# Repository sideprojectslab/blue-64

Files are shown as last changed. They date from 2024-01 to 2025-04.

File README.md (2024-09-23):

# Blue-64

If you would like to get in touch with the developer, please join the SPL [Discord](https://discord.gg/gJsCgebkDw) server.

[FULL README (PDF)](https://raw.githubusercontent.com/sideprojectslab/blue-64/main/doc/README.pdf)

Blue-64 is a plug & play bluetooth adapter for the Commodore 64 that plugs onto the keyboard header inside the computer and can control the keyboard lines and emulate keystrokes and joystick inputs. The goal of the project is to support two bluetooth controllers and a bluetooth keyboard simultaneously, in order to be able to controll the C64 completely wirelessly.

<figure align="center" id="blue_64_reg">
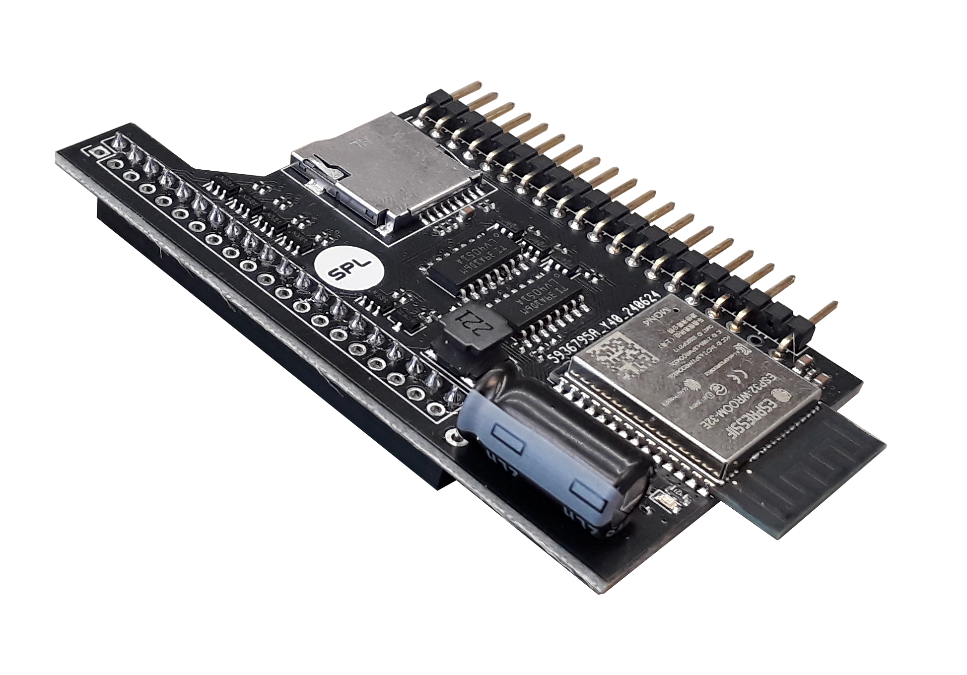
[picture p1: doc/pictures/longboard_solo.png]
	
	<figcaption>Blue-64 "Regular" Board</figcaption>
</figure>

<figure align="center" id="blue_64_dev">
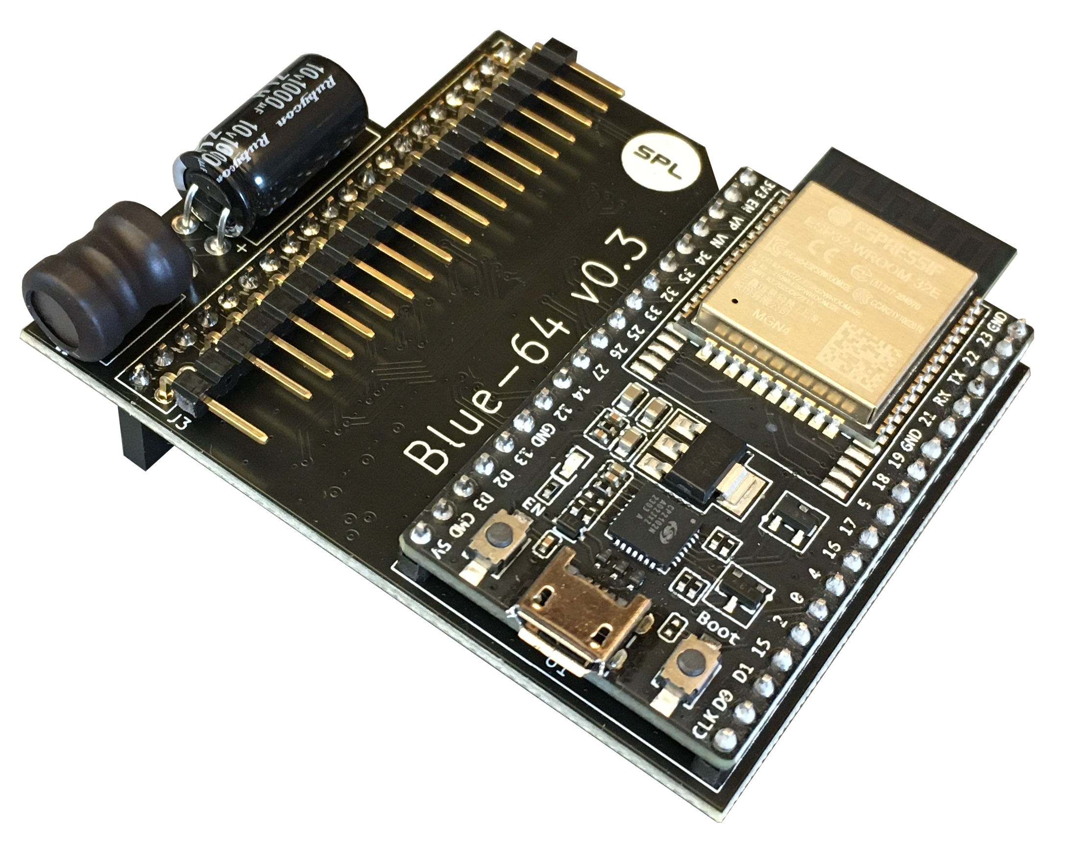
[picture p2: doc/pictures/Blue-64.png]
	
	<figcaption>Blue-64 Developer Board</figcaption>
</figure>

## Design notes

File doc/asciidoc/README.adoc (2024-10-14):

= Blue-64
:pdf-theme: resources/theme.yml
include::../resources/header.adoc[]
include::../resources/styles.adoc[]

ifndef::root[:root: ../../]
ifndef::firmware_update[:firmware_update:]
ifndef::misc[:misc:]
ifndef::mapping[:mapping:]
ifndef::menu[:menu:]

**Author:** Vittorio Pascucci

If you wish to get in touch with the developer, please join the SPL link:https://discord.gg/gJsCgebkDw[Discord] server.

**LICENSE:**
This work is provided under the **Creative Commons CC BY-NC-ND 4.0** License: +
https://creativecommons.org/licenses/by-nc-nd/4.0/

[cols="100a,113a"]
[width=80%]
[.center, frame=none, grid=none]
|===
|.Blue-64-developer ("Developer" Board)

|.Blue-64-regular ("Regular" Board)

|===

Blue-64 is a plug & play bluetooth adapter for the Commodore 64 that plugs onto the keyboard header inside the computer and can control the keyboard lines and emulate keystrokes and joystick inputs. The goal of the project is to support two bluetooth controllers and a bluetooth keyboard simultaneously, in order to be able to controll the C64 completely wirelessly.

Blue-64 can be purchased pre-assembled or as a DIY-Kit from these authorized shops:

- link:https://retro8bitshop.com/product/spl-blue-64-v1/[Retro8BitShop]
- link:https://www.retro-updates.com/product/15909946/blue-64-v1-0-plug-play-bluetooth-for-the-c64[Retro-Updates]
- link:https://restore-store.de/home/682-blue-64-v03.html?search_query=blue-64&results=7[Restore-Store]

Sales of Blue-64 by any shop other than the ones mentioned above may be in violation of the xref:#_license[License] terms and conditions and should be reported to the developer

<<<
toc::[]
<<<

== Pairing a Bluetooth Device
The Blue-64 is **always listening to incoming pairing requests** up to a maximum of three devices paired simultaneously. This means that it is sufficient to simply set a Bluetooth controller or keyboard in pairing mode and it will automatically pair with the Blue-64 without the need to set the Blue-64 itself in pairing mode.

include::mapping.adoc[]

include::menu.adoc[]

include::compatibility.adoc[]

include::firmware_update.adoc[]

include::misc.adoc[]

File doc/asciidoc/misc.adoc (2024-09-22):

include::../resources/header.adoc[]
include::../resources/styles.adoc[]
ifndef::root[:root: ../../]

== Installation & Precautions
Most notably, particular care shall be used when plugging the Blue-64 onto the motherboard, as the female connector on the Blue-64 has no alignment key and thus won't prevent incorrect installation. Always install the Blue-64 with the computer turned off and verify carefully that the connection to the motherboard header is properly aligned.

A step-by-steb video guide on how to assemble and install the Blue-64 board is available on link:https://youtu.be/yE2yL8-_jRQ?si=YmAZqs-F023yzRW5[YouTube]:
Users shall follow these instructions carefully and fully understand the circuit's limitations before installing and/or using it.

Incorrect installation of the board supply or failure to comply with the recommended operating conditions may result in damage to the board and/or to the computer, with risk of overheating, fire and/or explosion.

== License
License information is included on top of all software source files as well as in all schematics. Files that do not contain explicit licensing information are subject to the licensing terms stated in the LICENSE.txt provided in the main project folder:

Unless stated otherwise in individual files, all hardware design Schematics, Bill of Materials, Gerber files and manuals are licensed under Creative Commons Attribution-NonCommercial-NoDerivatives 4.0 International. To view a copy of this license, visit http://creativecommons.org/licenses/by-nc-nd/4.0/

Unless otherwise stated in individual files, all software source files are Licensed under the Apache License, Version 2.0. You may obtain a copy of this license at http://www.apache.org/licenses/LICENSE-2.0

== Disclaimer
All material is provided on an 'AS IS' BASIS, WITHOUT WARRANTIES OR
CONDITIONS OF ANY KIND in accordance to the license deed applicable to
each individual file.

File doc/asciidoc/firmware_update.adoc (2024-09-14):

include::../resources/header.adoc[]
include::../resources/styles.adoc[]
ifndef::root[:root: ../../]

:on-screen-menu: xref:{menu}#menu[on-screen menu]
:github: link:https://github.com/sideprojectslab/blue-64/[GitHub]

== Firmware Update
Firmware binaries can be found in the "Releases" section of the project's {github} page. The three files in the "binaries.zip" folder are necessary to perform a firmware update:
- bootloader.bin
- partition-table.bin
- application.bin

=== "Developer Boards" (up to v0.3)

NOTE: It is not possible to "brick" the "Developer Board", if something fails it will always be able to re-try flashing new firmware.

. Connect the Blue-64 to the PC through a data-capable Micro-USB cable. The power led on the Blue-64 board shall turn on.

. Download and install the CP210X Universal Windows Drivers for the on-board programmer at this website:
https://www.silabs.com/developers/usb-to-uart-bridge-vcp-drivers?tab=downloads

. Open the Espressif Online Tool in a web browser at the following link: https://espressif.github.io/esptool-js/

+
.ESP Online Tool: Start Screen
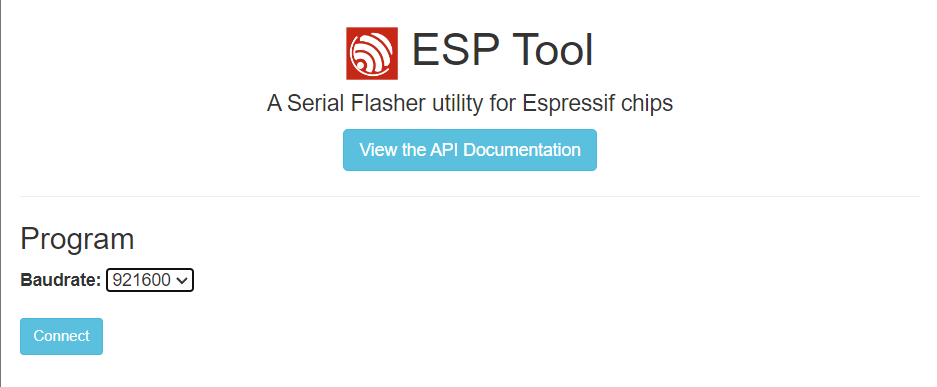
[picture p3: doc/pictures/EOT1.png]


. Select the highest Baudrate and click "connect". The dialog shown below shall appear, allowing the selection of the currently connected Blue-64
+
.ESP Online Tool: Device Selection
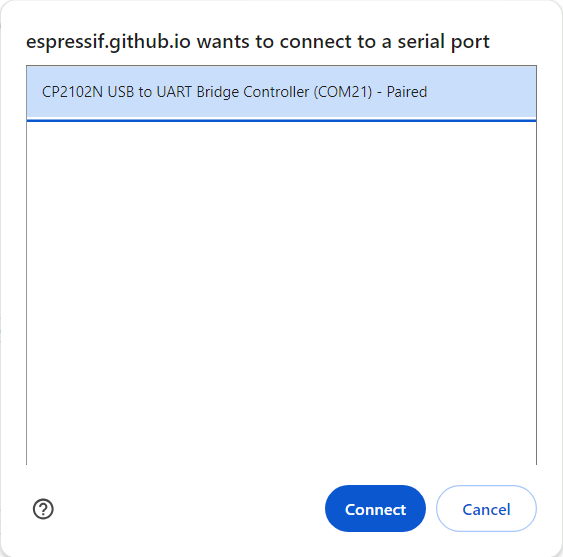
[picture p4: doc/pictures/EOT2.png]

+
NOTE: if pressing the "connect" button on the start screen does not open the dialog above, please try opening the web page with a different web browser.

. Once connected, add the update files at the appropriate addresses so that the page looks like the picture below
+
.ESP Online Tool: Binary Upload
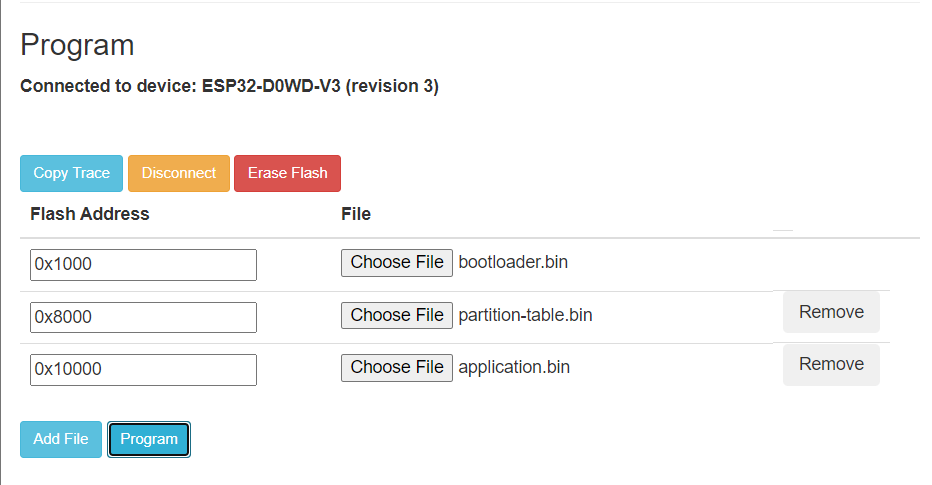
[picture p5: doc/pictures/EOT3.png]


. Press "program". If everything went well, the console below should look like the picture below
+
.ESP Online Tool: Successful Update
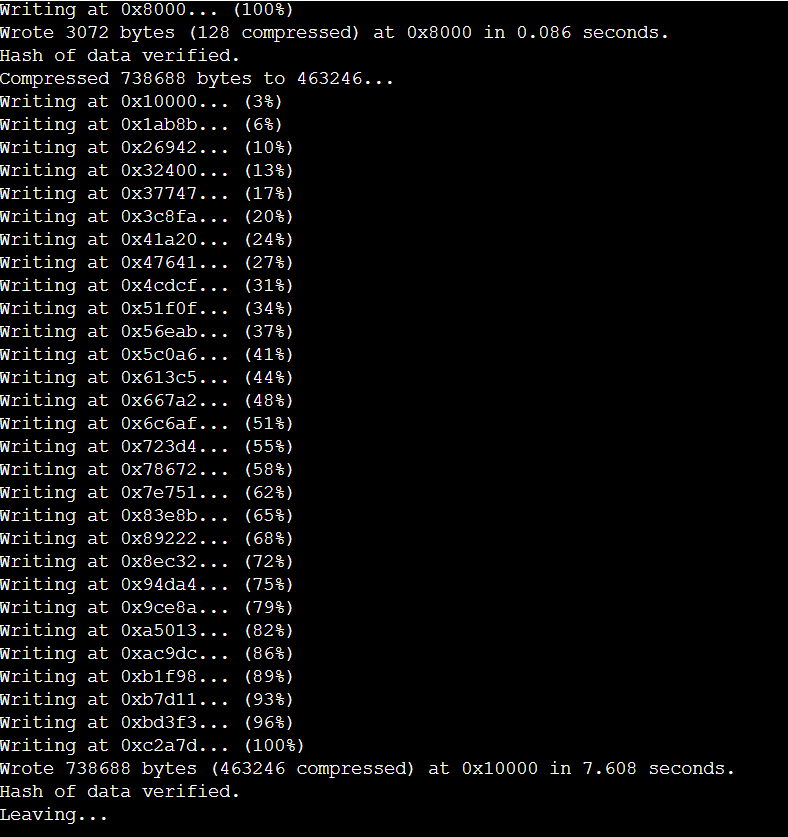
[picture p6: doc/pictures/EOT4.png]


=== "Regular Boards" (v1.0 and above)
Regular boards are updated via the Micro SD card slot.

. Format a Micro SD card to FAT32.
. Copy application.bin to the root of the SD card.
. Switch off the C64 and insert the SD card into the dedicated slot on the Blue-64 board.
. Switch on the C64, after a few seconds an on-screen prompt will state that the update has started. If the prompt does not appear within 10 seconds it means that the ESP cannot mount the SD card or cannot find the application.bin file in its root.

NOTE: DO NOT POWER OFF THE C64 DURING THIS PROCESS UNLESS IT TAKES MORE THAN 10 MINUTES

. After about a minute an on-screen prompt will communicate the result of the update procedure.
. Switch off the C64, remove the SD-Card and switch on again.
, Navigate to the Device-Info entry on the {on-screen-menu} and verify that the latest version is currently running on the device.

NOTE: In the extremely unlikely event that the device becomes "bricked" (as in not functioning properly and also not being able to accept new firmware), it is **always possible** to flash new firmware via the UART header on the bottom of the board. This can be done with an inexpensive USB-to-UART adapter and basic soldering skills. Please get in touch with the developer for support.

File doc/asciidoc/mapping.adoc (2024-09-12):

include::../resources/header.adoc[]
include::../resources/styles.adoc[]
ifndef::root[:root: ../../]
ifndef::menu[:menu: menu.adoc]

:on-screen-menu: xref:{menu}#menu[on-screen menu]
:vice: xref:https://vice-emu.sourceforge.io/vice_1.html#SEC11[Vice]

== Controller Mapping (xInput)

The following key mappings directly apply to "xInput" devices, such as the Xbox-One controller. Different controllers such as the Switch controller and the Playstation 4/5 controller have nearly identical mapping, where buttons in similar positions perform the same function as their xInput counterparts

[%header, cols="^.^, ^.^, ^.^"]
[width=80%]
[.center]
|===
| Joystick | Controller  | Controller Alt.
| UP       | D-Pad UP    | Button B
| DOWN     | D-Pad DOWN  | Button X
| LEFT     | D-Pad LEFT  | Left Analog
| RIGHT    | D-Pad RIGHT | Left Analog
| FIRE     | Button A    | Button Y (Autofire)
|===

[[button-map]]
Controller buttons not mentioned in the table above can be mapped to trigger any keyboard keystroke through the {on-screen-menu}. Default Controller-Keyboard mappings are reported below:

[%header, cols="^.^, ^.^"]
[width=80%]
[.center]
|===
| Keyboard | Controller
| SPACE    | Menu Button
| F1       | Right Shoulder
|===

[[autofire]]
=== Autofire
The "Y Button" is dedicated to autofire, which can be configured from inactive to 10Hz (100ms) fire-rate through the {on-screen-menu}

[[swap-ports]]
=== Swapping Joystick Ports
Joystick ports assigned to the connected bluetooth controllers can be swapped with the "View + Y" key combination on the controller.
If two controllers are currently connected, only the controller currently assigned to joystick port 2 can swap the ports (to prevent pesky little siblings or partners from swapping ports in-game)

[[keyboard-map]]
== Keyboard Mapping
At the moment Blue-64 **only supports the English US layout**. The key mapping can be switched between "symbolic" and "positional ({vice})" through the {on-screen-menu}. With "symbolic" mapping the keys on the bluetooth keyboard do exactly what they say on the label, including their "shift" function (if applicable) with a few exceptions:

[%header, cols="^.^, ^.^"]
[width=80%]
[.center]
|===
| En-US Key (symbolic) | C64 Key
| '~'             | Arrow Left
| '\'             | Arrow Up
| 6+Shift         | £
| Tab / Shift+Tab | Stop / Run
| Esc             | Restore
| Delete, F12     | Clear
| Home, F9        | Home
| Insert, F10     | Insert
| Start (Windows) | Commodore
| Shift+'\'       | Pi
|===

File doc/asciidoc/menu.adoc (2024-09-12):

include::../resources/header.adoc[]
include::../resources/styles.adoc[]
ifndef::root[:root: ../../]
ifndef::mapping[:mapping: mapping.adoc]

:keyboard-mapping-profile: xref:{mapping}#keyboard-map[keyboard mapping profile]
:unused-controller-buttons: xref:{mapping}#button-map[unused controller buttons]
:autofire: xref:{mapping}#autofire[Autofire]

[[menu]]
== On-Screen Menu & Additional Functions
Blue-64 has an internal menu that is visualized by printing text on screen. The menu allows typing and executing frequently used macros like loading the tape, loading and/or running programs from disk drive etc. as well as configuring additional preferences.

=== Navigating the On-Screen Menu (xInput)
. The on-screen menu can only be navigated via a connected bluetooth controller and/or keyboard and **not with the native C64 keyboard**
. In order to **Enter** the on-screen menu simply press "View + A/B" on the controller or "Alt/AltGr + Up/Down/Left/Right Arrow" on the keyboard, and menu entries will start printing on screen
. Once inside the on-screen menu, in order to move or **"Cycle"** through the varius entries press "View + A/B" on the controller or "Alt/AltGr + Up/Down/Left/Right Arrow" on the keyboard
. In order to **Exit** the on-screen menu or any submenu press "View + X" on the controller or "Alt/AltGr + Backspace" on the keyboard. This will bring the menu "back one level" or produce a blank screen when exiting the menu completely
. In order to **Confirm** a choice press "View + Menu" on the controller or "Alt/AltGr + Enter" on the keyboard

//-

[%header, cols="^.^, ^.^, ^.^"]
[width=80%]
[.center]
|===
| Function         | Controller Button(s) | Keyboard Key(s)
| Enter/Cycle Menu | View + A/B           | Alt/AltGr + Up/Down/Left/Right Arrow
| Confirm Menu     | View + Menu          | Alt/AltGr + Enter
| Exit Menu        | View + X             | Alt/AltGr + Backspace
|===

NOTE: Pressing "View + Menu" on the controller or "Alt/AltGr + Enter" on the keyboard outside of the on-screen menu will launch the last displayed entry. If no entry was yet displayed, the **"LOAD TAPE"** entry will be launched.

NOTE: Please beware that the "view" and "menu" buttons may be called differently on non xInput devices but are generally in similar positions

NOTE: Please beware that some controllers, such as 8bitDo or Switch controllers have X-Y and A-B button labels swapped compared to a regular Xbox controllers. What matters in this case is the buttons' position, not the label, so for instance the A button will always be the one at the bottom regardless of the label

=== Loading Tape/Disk
The first entries of the on-screen menu allow to quickly launch commonly used commands:

. **LOAD TAPE:** LOAD
. **LOAD DISK:** LOAD$,8
. **RUN DISK:** LOAD*,8

In order to launch these commands:

. **Enter** the on-screen menu
. **Cycle** to find the desired command
. **Confirm** (The appropriate command will be automatically typed on-screen and run)

NOTE: When loading the tape it is often necessary to press "space" on the keyboard to run the first program. The "space" key is also mapped by default on the "Menu" button of the controller

=== Checking Device information
The **"DEVICE INFO"** menu entry shows relevant information about the device, including the firmware version. In order to display the device info:

. **Enter** the on-screen menu
. **Cycle** to find the "DEVICE INFO" entry
. **Confirm**
. Once the device information is plotted on screen, **Exit** the (sub)menu

=== Selecting Keyboard Mapping
The {keyboard-mapping-profile} can be switched between "symbolic" and "positional". In order to select the desired profile:

. **Enter** the on-screen menu
. **Cycle** to find the "KEYBOARD MAPPING" entry
. **Confirm** to enter the submenu
. **Cycle** to select the desired profile
. **Confirm** (this will also exit the submenu)
. **Exit** the menu

=== Configuring Autofire Rate
{autofire} rate can be configured between "none" (single shot) to 10Hz (10 shots per second) through the on-screen menu. In order to configure the autofire rate:

. **Enter** the on-screen menu
. **Cycle** to find the "AUTOFIRE RATE" entry
. **Confirm** to enter the submenu
. **Cycle** to select the desired rate
. **Confirm** (this will also exit the submenu)
. **Exit** the menu

=== Mapping Controller Buttons to Keyboard Keys
All {unused-controller-buttons} can be remapped to trigger keyboard keystrokes through the on-screen menu. In order to assign keystrokes to controller buttons:

. **Enter** the on-screen menu
. **Cycle** to find the "CONTROLLER MAPPING" entry
. **Confirm** to enter the submenu
. **Cycle** to find the controller button you wish to assign a keystroke to

NOTE: While cycling through the controller buttons, the currently assigned keystroke is shown on the right. If no keystroke is assigned to the currently displayed button the **""** (empty) symbol is shown

. **Confirm** to select the currently displayed controller button
.. To leave the current association unchanged **Exit** the (sub)menu immediately
.. To remove the current keystroke association **Confirm** immediately
.. If a bluetooth keyboard is connected, press the desired key (including modifiers) on the bluetooth keyboard, then **Confirm**
.. If no bluetooth keyboard is connected, **Cycle** until the desired key is displayed on the right, then **Confirm**.
. Any of the aforementioned actions will also deselect the current button
. **Cycle** to find another desired button to assign a keystroke to
. Repeat the steps above until all desired buttons have been mapped
. **Exit** the (sub)menu

=== Restoring Default Settings
Default settings can be restored through the on-screen menu. In order to restore default settings:

. **Enter** the on-screen menu
. **Cycle** to find the "RESTORE DEFAULTS" entry
. **Confirm** to enter the submenu
. **Cycle** to select "YES"
. **Confirm** (this will also exit the submenu)
. **Exit** the menu

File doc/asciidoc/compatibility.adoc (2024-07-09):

include::../resources/header.adoc[]
include::../resources/styles.adoc[]
ifndef::root[:root: ../../]

== Compatibility

=== C64 Motherboard Compatibility
Blue-64 has been verified to be compatible with the following C64 motherboard revisions:

[%header, cols="^.^1, ^.^2"]
[width=80%]
[.center]
|===
| Motherboard | Notes
| 250407  | -
| 250425  | -
| 250466  | -
| 326298  | -
| ku14194 | -

| 250469
| The developer version of Blue-64 needs a xref:#shortboard-adapter[special adapter] and the female header is mounted upside down
|===

.Shortboard Adapter
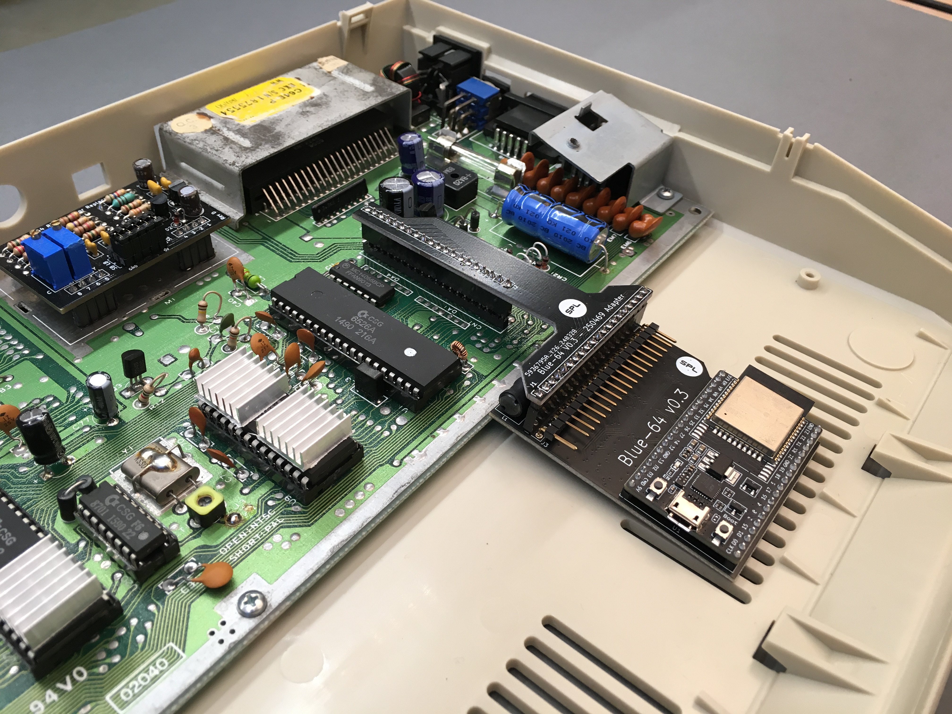
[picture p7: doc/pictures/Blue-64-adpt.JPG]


=== Device Support
Blue-64 is based on the link:https://bluepad32.readthedocs.io/en/latest/[bluepad32] library from Ricardo Quesada. As such it supports the exact same devices (bluetooth controllers & keyboards) as bluepad32.

Supported Controllers: https://bluepad32.readthedocs.io/en/latest/supported_gamepads/

Supported Keyboards: https://bluepad32.readthedocs.io/en/latest/supported_keyboards/

=== Limitations
- At the moment Blue-64 only supports Bluetooth Low Energy (BLE) devices.

- Blue-64 can only interact with the lines present on the keyboard header, thus it has no access to the "paddle" control lines. Therefore it cannot emulate the Commodore mouse, paddle controls, and does **not support additional joystick fire buttons** (other than the primary one) that are based on paddle control. Luckily though, most games supporting additional fire buttons also map them to keyboard keys, which can be mapped to controller buttons through the on-screen menu.

- Blue-64 can only perform **one keystroke at a time**, with the exception of modifier keys like ``control``, ``commodore``, ``left-shift`` and ``restore`` which can all be pressed simultaneously. In order to overcome this limitation, when multiple regular keys are pressed simultaneously, Blue-64 **always performs the latest keypress**. At the same time it remembers the order of the last 8 simultaneous keystrokes, in order to trigger new keystrokes in the inverse order when the current one is released.

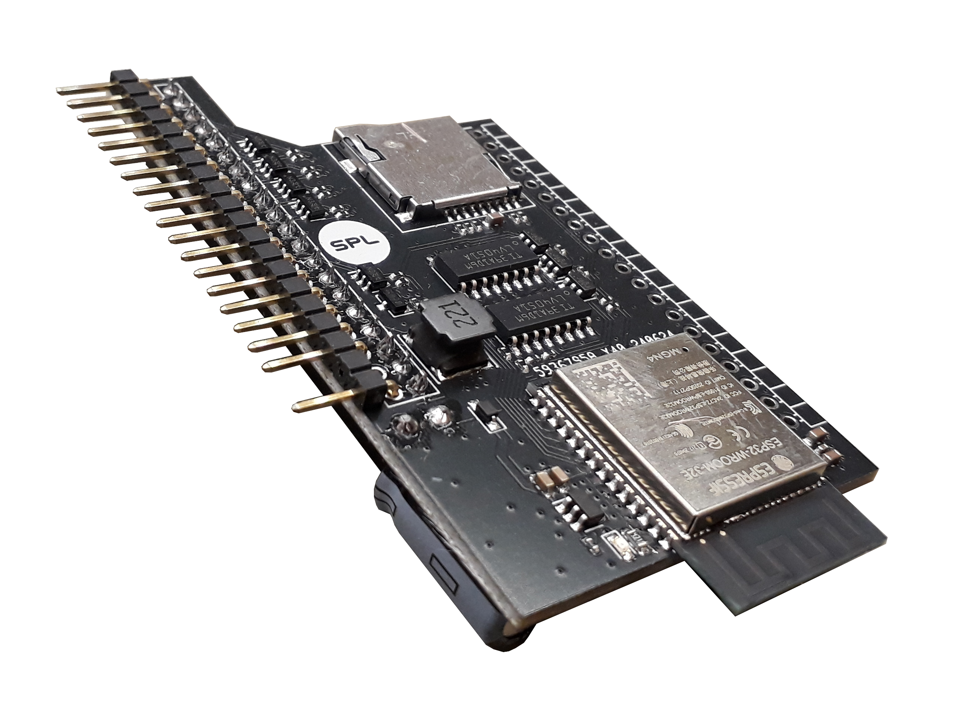
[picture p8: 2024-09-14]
doc/pictures/shortboard_solo.png

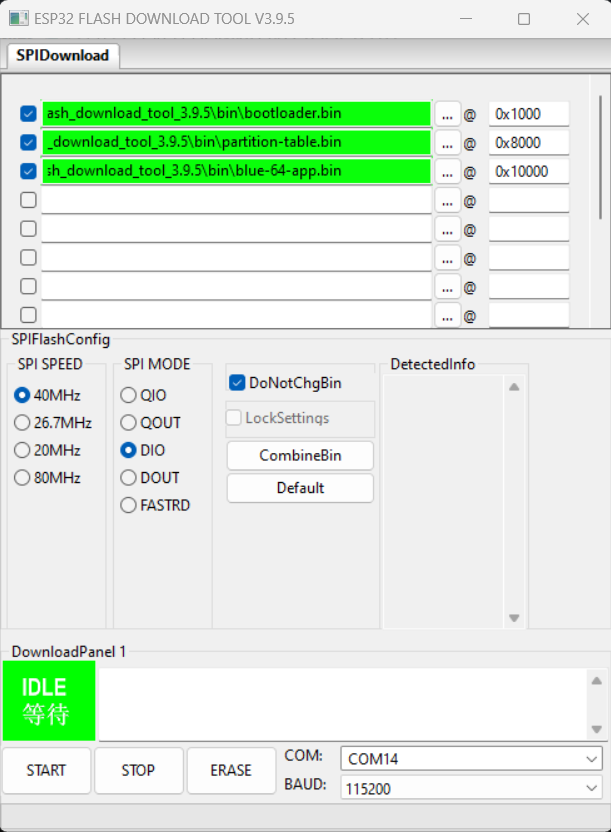
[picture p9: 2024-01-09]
doc/pictures/flash_tool.png

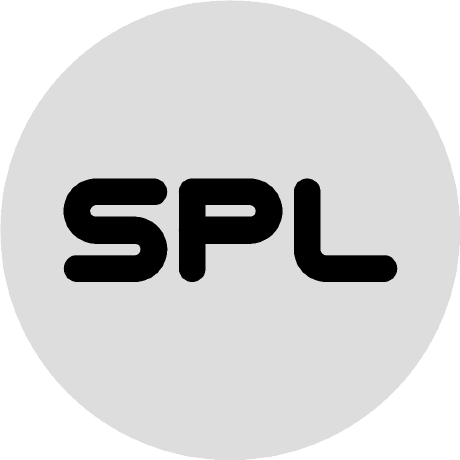
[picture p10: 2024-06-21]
doc/pictures/spl.png

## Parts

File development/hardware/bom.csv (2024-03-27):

Comment | DNP | Designator | Footprint
10ZLH1000MEFC8X16 |  | C1 | eas_cdb_capacitor:10ZLH1000MEFC8X16-Horiz-L
B5819WS-TP |  | D1 | eas_cdb_diode:D_SOD-323_HandSoldering
BC817-40,235 |  | Q1 | eas_cdb_bjt:SOT-23
RC0603FR-0710KL |  | R1, R2, R3, R4, R5, R6, R7, R8, R9, R10, R11, R12, R13, R14, R15, R16, R17, R18, R19, R20, R21 | eas_cdb_resistor:R_0603_1608Metric
BC817DS,115 |  | U2, U3, U4, U5, U6 | eas_cdb_bjt:TSOP-6_1.65x3.05mm_P0.95mm
MC74LVXT4051DR2G |  | U7, U8 | eas_cdb_switch_solid_state:SOIC-16_3.9x9.9mm_P1.27mm
TS5A1066DBVR |  | U9, U10, U11 | eas_cdb_switch_solid_state:SOT-23-5

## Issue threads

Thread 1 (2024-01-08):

C128 keyboard support?

banman11, 2024-01-08:
Hello,

First up, I'd like to say this looks like a very interesting project.

I was wondering how hard would it be to add a few extra keystrokes to support the very few extra keys on a C128 keyboard?

sideprojectslab, 2024-01-08:
Hello, as long as the hardware allows it it should be no problem. However I
need to look into the keyboard connector of the c128 to say for sure :)

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

banman11, 2024-01-08:
The keyboard is basically the same thing as a C64 with a few extra lines. One is hardwired I believe. That is the 40/80 switch.
The actual interface is a sort of square 25 way D female connector.
The Commodore engineer's tried to make it as easy as possible to use off the shelf parts.

Here is an example of a third party adaptor which would very easily plug straight into your project.

https://www.tindie.com/products/retrofletch/c64-keyboard-to-c128-adaptor-commodore-128-c128d/

Just a side note with a small wiring rearrangement of the keyboard lines a c16/plus4 keyboard should work just fine as well.

https://www.pcbway.com/project/shareproject/C64_Keyboard.html

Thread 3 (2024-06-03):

Does it come preflashed?

ssuukk, 2024-06-03:
Hi!

I've just received an assembled version of Blue 64. The passthrough seems to work ok, as I can type on C64 keyboard, but the device itself keeps sending ghost keypresses (probably every second, not exactly random, the letters seem to repeat). Do I have to flash it? Can I debug it somehow?

sideprojectslab, 2024-06-10:
Hi, sorry for the late reply. Either the board is defective or (more likely) it is stuck in a boot loop. Normally the boards come already flashed but who knows, yours might have been corrupted somehow. There are a few steps you can take: first of all I would suggest to follow the instructions on the readme here on github and make sure to flash the latest version of the firmware. If that doesn't fix your issue we can go on with debugging. Would you be able to build the project yourself on Windows with some guidance? This would make the debugging process very easy, otherwise I will provide you with a debug-enabled version of the firmware which will log all diagnostics on a UART terminal through the USB port

ssuukk, 2024-06-10:
Sure, I have a few ESP32 projects, so I guess I can manage with debuggin this one!

sideprojectslab, 2024-06-11:
allright perfect, would you like to join the discord server linked in the project readme? then we can troubleshoot more easily :)

ssuukk, 2024-06-11:
sure, which one? :D

sideprojectslab, 2024-06-14:
This one: https://discord.com/invite/gJsCgebkDw I am not aware of any others :D

ssuukk, 2024-06-22:
Oh, there's thousands of them! Check out this cool one about Meatloaf - a C64 cloud drive on ESP!

Closed 2024-12-27.

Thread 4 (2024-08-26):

Compatibility with Ultimate64 Elite?

pwartbichler, 2024-08-26:
Hi,
Is this project compatible with the current version of the Ultimate64 Elite, and will it support upcoming versions?

Thanks!

sideprojectslab, 2024-08-26:
Hello,

The Blue-64 can be used on the current version of the U64 by means of a
ribbon cable to relocate the board in an appropriate position. Gideon was
not planning to support reading joystick data from the keyboard header in
future version of the U64, which would make the blue-64 much less useful.
Fortunately I have been talking to him and he seemed to confirm that it
would be possible to enable this feature via software in future versionn of
the U64, so I'll keep you posted on the progress.

The best way to stay up to date is to join our discord server, where you
can also ask around other users that have been experimenting with the
Blue-64.

https://discord.gg/w6gvqyBG

Kind regards,

On Mon, Aug 26, 2024 at 10:39 AM Patrik Wartbichler <
***@***.***> wrote:

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

pwartbichler, 2024-08-27:
Thanks for the update, this sounds very promising 👍

Closed 2024-12-27.

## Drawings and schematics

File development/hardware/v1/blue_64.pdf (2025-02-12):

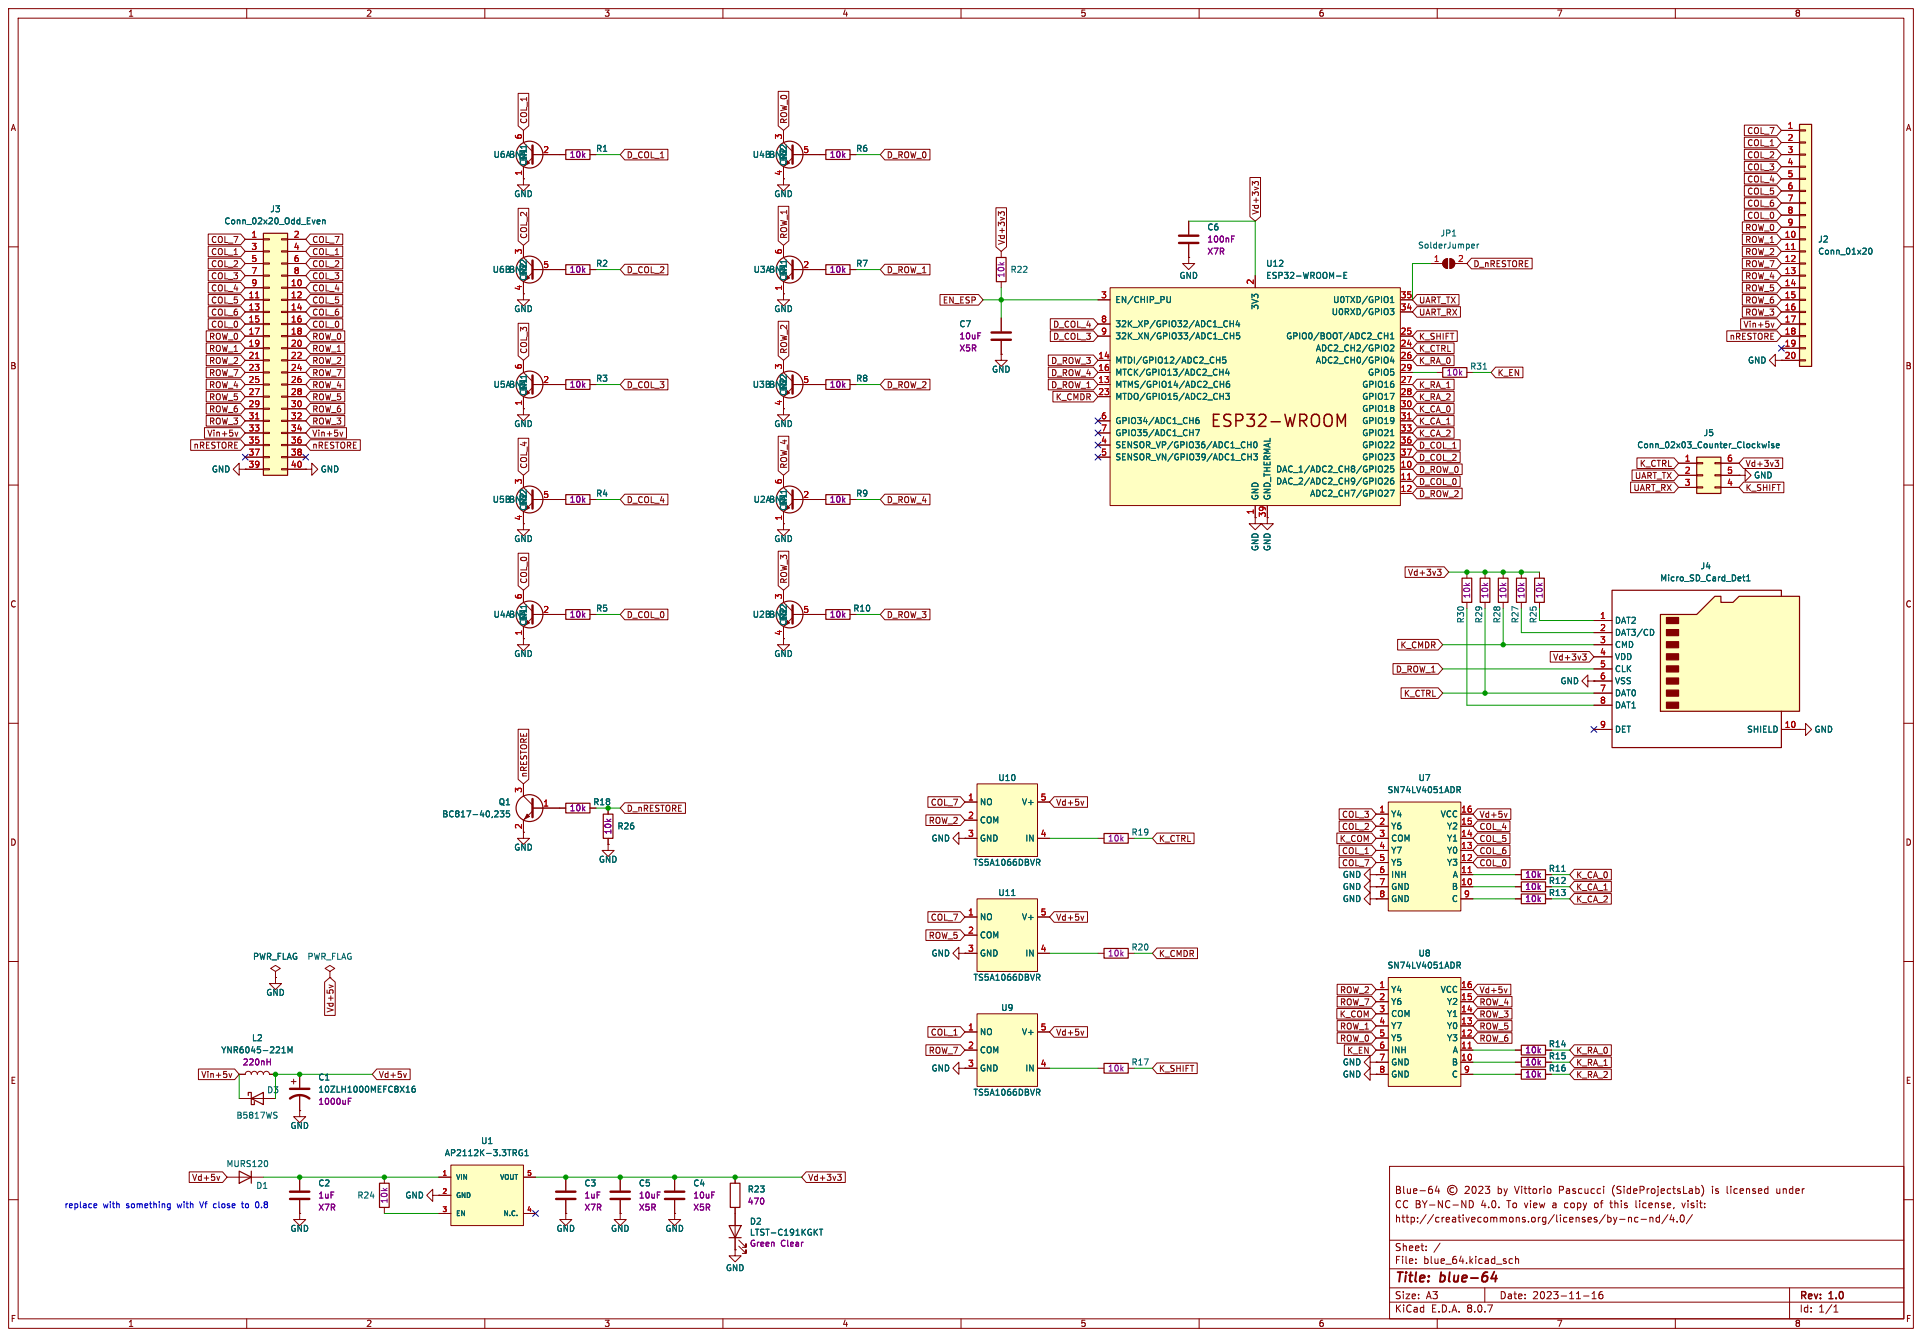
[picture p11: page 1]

10 DAT3/CD 2 CMD 3 VDD 4 CLK 5 VSS 6 DAT0 7 DAT1 8 DET 9

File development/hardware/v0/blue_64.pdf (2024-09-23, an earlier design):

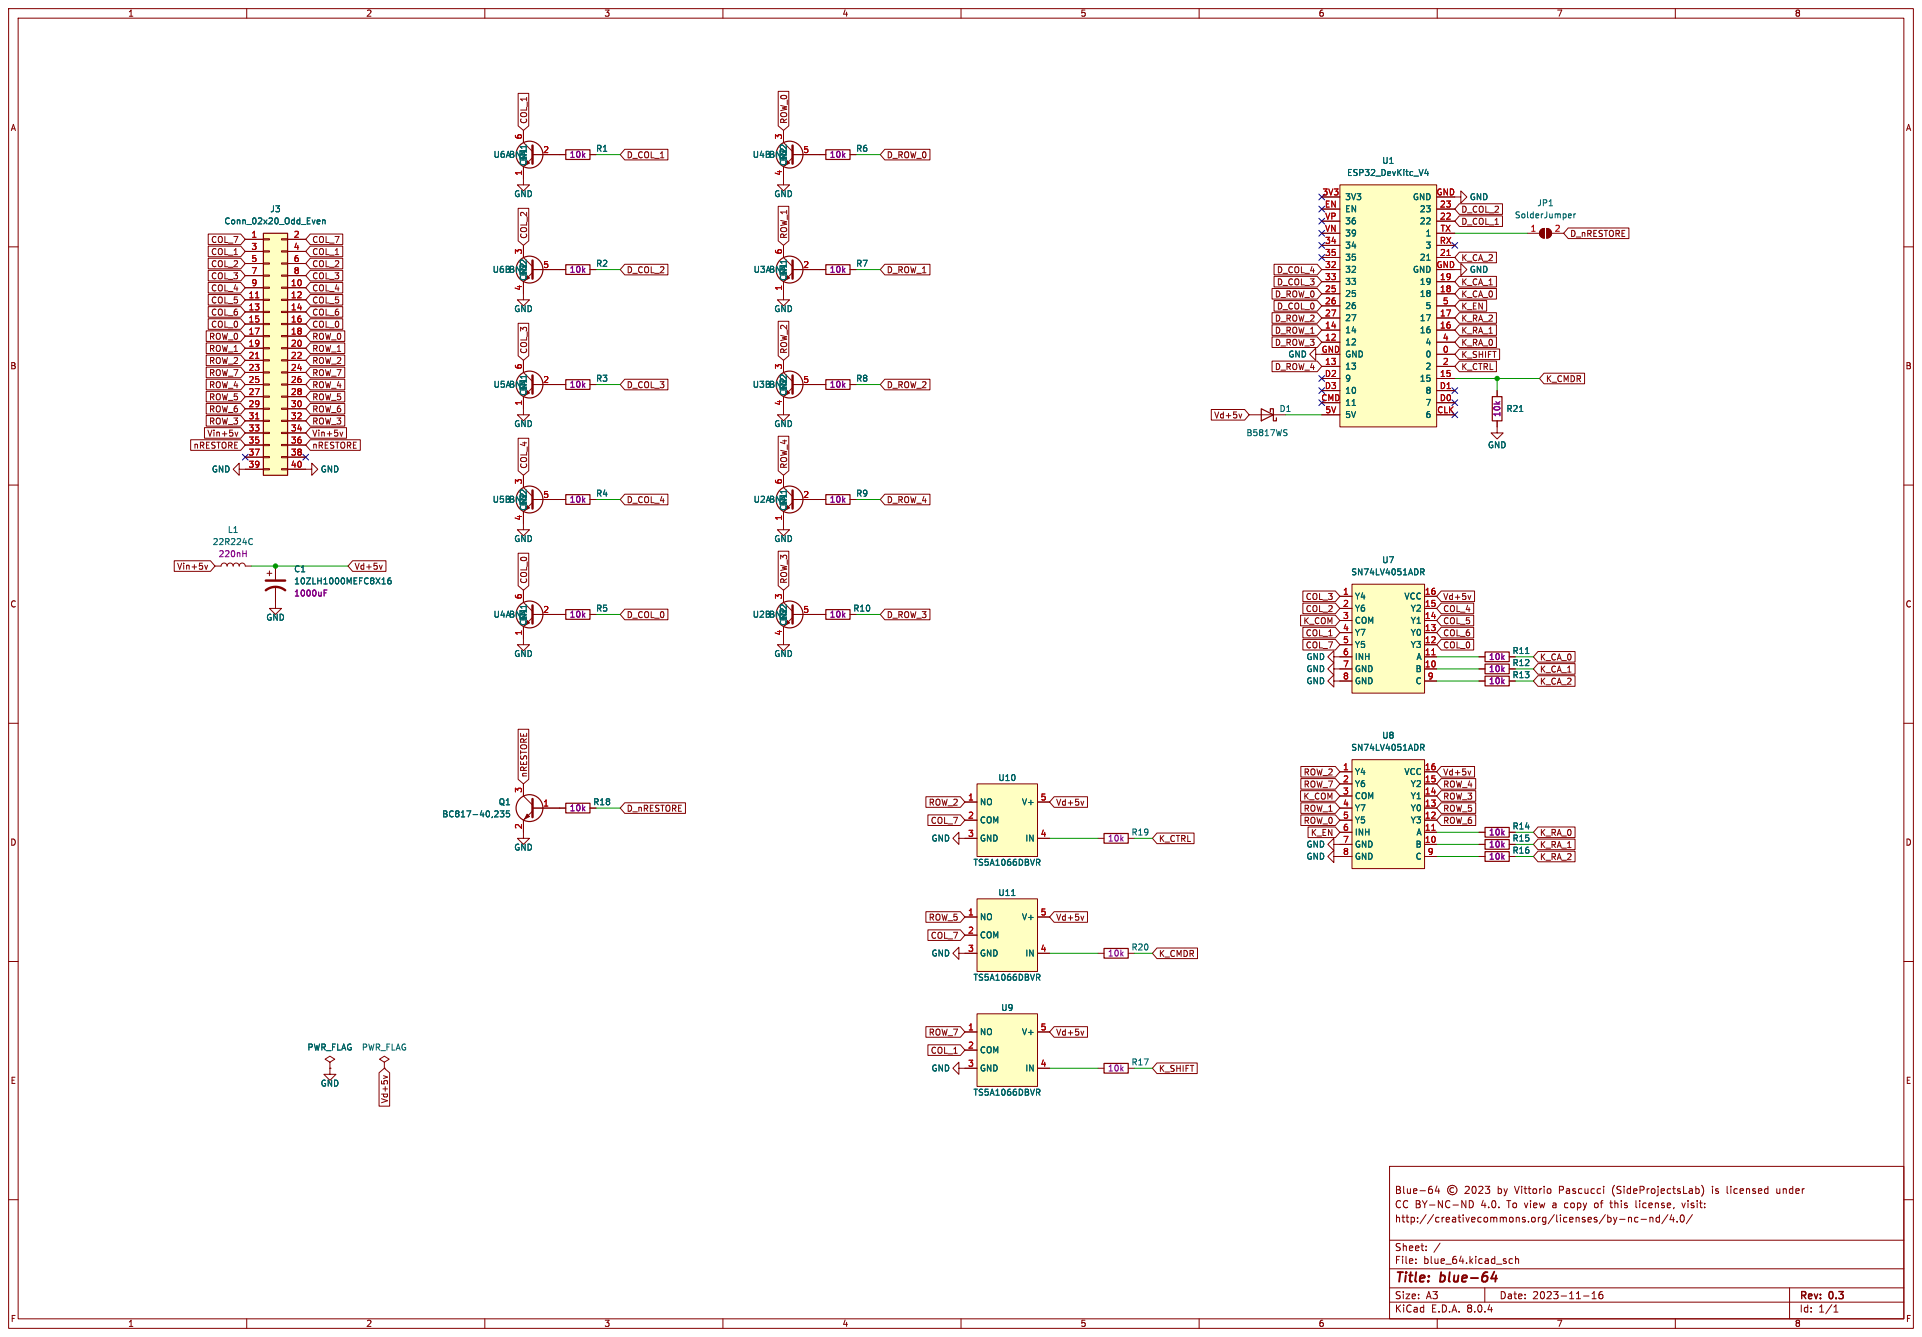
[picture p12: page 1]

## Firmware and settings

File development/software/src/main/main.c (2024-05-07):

//----------------------------------------------------------------------------//
//         .XXXXXXXXXXXXXXXX.  .XXXXXXXXXXXXXXXX.  .XX.                       //
//         XXXXXXXXXXXXXXXXX'  XXXXXXXXXXXXXXXXXX  XXXX                       //
//         XXXX                XXXX          XXXX  XXXX                       //
//         XXXXXXXXXXXXXXXXX.  XXXXXXXXXXXXXXXXXX  XXXX                       //
//         'XXXXXXXXXXXXXXXXX  XXXXXXXXXXXXXXXXX'  XXXX                       //
//                       XXXX  XXXX                XXXX                       //
//         .XXXXXXXXXXXXXXXXX  XXXX                XXXXXXXXXXXXXXXXX.         //
//         'XXXXXXXXXXXXXXXX'  'XX'                'XXXXXXXXXXXXXXXX'         //
//----------------------------------------------------------------------------//
//             Copyright 2023 Vittorio Pascucci (SideProjectsLab)             //
//                  Based on original work by Ricardo Quesada                 //
//                                                                            //
// Licensed under the Apache License, Version 2.0 (the "License");            //
// you may not use this file except in compliance with the License.           //
// You may obtain a copy of the License at                                    //
//                                                                            //
//     http://www.apache.org/licenses/LICENSE-2.0                             //
//                                                                            //
// Unless required by applicable law or agreed to in writing, software        //
// distributed under the License is distributed on an "AS IS" BASIS,          //
// WITHOUT WARRANTIES OR CONDITIONS OF ANY KIND, either express or implied.   //
// See the License for the specific language governing permissions and        //
// limitations under the License.                                             //
//----------------------------------------------------------------------------//

#include <stdlib.h>

#include <btstack_port_esp32.h>
#include <btstack_run_loop.h>
#include <btstack_stdio_esp32.h>
#include <uni.h>

#include "sdkconfig.h"

// Sanity check
#ifndef CONFIG_BLUEPAD32_PLATFORM_CUSTOM
#error "Must use BLUEPAD32_PLATFORM_CUSTOM"
#endif

// Defined in my_platform.c
struct uni_platform* c64b_platform_create(void);

int app_main(void) {
    // hci_dump_open(NULL, HCI_DUMP_STDOUT);

    // Don't use BTstack buffered UART. It conflicts with the console.
#ifdef CONFIG_ESP_CONSOLE_UART
#ifndef CONFIG_BLUEPAD32_USB_CONSOLE_ENABLE
    btstack_stdio_init();
#endif  // CONFIG_BLUEPAD32_USB_CONSOLE_ENABLE
#endif  // CONFIG_ESP_CONSOLE_UART

    // Configure BTstack for ESP32 VHCI Controller
    btstack_init();

    // hci_dump_init(hci_dump_embedded_stdout_get_instance());

    // Must be called before uni_init()
    uni_platform_set_custom(c64b_platform_create());

    // Init Bluepad32.
    uni_init(0 /* argc */, NULL /* argv */);

    // Does not return.
    btstack_run_loop_execute();

    return 0;
}

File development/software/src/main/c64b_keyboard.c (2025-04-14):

//----------------------------------------------------------------------------//
//         .XXXXXXXXXXXXXXXX.  .XXXXXXXXXXXXXXXX.  .XX.                       //
//         XXXXXXXXXXXXXXXXX'  XXXXXXXXXXXXXXXXXX  XXXX                       //
//         XXXX                XXXX          XXXX  XXXX                       //
//         XXXXXXXXXXXXXXXXX.  XXXXXXXXXXXXXXXXXX  XXXX                       //
//         'XXXXXXXXXXXXXXXXX  XXXXXXXXXXXXXXXXX'  XXXX                       //
//                       XXXX  XXXX                XXXX                       //
//         .XXXXXXXXXXXXXXXXX  XXXX                XXXXXXXXXXXXXXXXX.         //
//         'XXXXXXXXXXXXXXXX'  'XX'                'XXXXXXXXXXXXXXXX'         //
//----------------------------------------------------------------------------//
//             Copyright 2023 Vittorio Pascucci (SideProjectsLab)             //
//                                                                            //
// Licensed under the Apache License, Version 2.0 (the "License");            //
// you may not use this file except in compliance with the License.           //
// You may obtain a copy of the License at                                    //
//                                                                            //
//     http://www.apache.org/licenses/LICENSE-2.0                             //
//                                                                            //
// Unless required by applicable law or agreed to in writing, software        //
// distributed under the License is distributed on an "AS IS" BASIS,          //
// WITHOUT WARRANTIES OR CONDITIONS OF ANY KIND, either express or implied.   //
// See the License for the specific language governing permissions and        //
// limitations under the License.                                             //
//----------------------------------------------------------------------------//

#include <uni.h>

#include "freertos/FreeRTOS.h"
#include "freertos/task.h"

#include "c64b_keyboard.h"
#include "driver/gpio.h"

#define ESC_LEN_MAX 6
#define SHIFT_COL   1
#define SHIFT_ROW   7
#define NUM_KEYS    116

// the "~" character is used to "escape" complex characters.
// It is not present on the c64 keyboard and thus is free to use

const t_c64b_key_id KEY_IDS[NUM_KEYS] =
{
	{" "       , 7, 4, false, false, true },

	{"~f1~"    , 0, 4, false, false, false},
	{"~f2~"    , 0, 4, true , false, false},
	{"~f3~"    , 0, 5, false, false, false},
	{"~f4~"    , 0, 5, true , false, false},
	{"~f5~"    , 0, 6, false, false, false},
	{"~f6~"    , 0, 6, true , false, false},
	{"~f7~"    , 0, 3, false, false, false},
	{"~f8~"    , 0, 3, true , false, false},

	{"~up~"    , 0, 7, true , false, false},
	{"~dn~"    , 0, 7, false, false, false},
	{"~rr~"    , 0, 2, false, false, false},
	{"~ll~"    , 0, 2, true , false, false},

	{"~lsh~"   , 1, 7, false, false, false},
	{"~rsh~"   , 6, 4, false, false, false},
	{"~cmdr~"  , 7, 5, false, false, false},
	{"~ctrl~"  , 7, 2, false, false, false},
	{"~run~"   , 7, 7, true , false, false},
	{"~stop~"  , 7, 7, false, false, false},
	{"~ret~"   , 0, 1, false, false, false},
	{"~del~"   , 0, 0, false, false, false},
	{"~clr~"   , 6, 3, true , false, false},
	{"~inst~"  , 0, 0, true , false, false},
	{"~home~"  , 6, 3, false, false, false},

	{"0"       , 4, 3, false, false, true },
	{"1"       , 7, 0, false, false, true },
	{"2"       , 7, 3, false, false, true },
	{"3"       , 1, 0, false, false, true },
	{"4"       , 1, 3, false, false, true },
	{"5"       , 2, 0, false, false, true },
	{"6"       , 2, 3, false, false, true },
	{"7"       , 3, 0, false, false, true },
	{"8"       , 3, 3, false, false, true },
	{"9"       , 4, 0, false, false, true },

	{"/"       , 6, 7, false, false, true },
	{"="       , 6, 5, false, false, true },
	{";"       , 6, 2, false, false, true },
	{"*"       , 6, 1, false, false, true },
	{"^"       , 6, 0, false, false, true }, // this replaced the pound symbol
	{","       , 5, 7, false, false, true },
	{"@"       , 5, 6, false, false, true },
	{":"       , 5, 5, false, false, true },
	{"."       , 5, 4, false, false, true },
	{"-"       , 5, 3, false, false, true },
	{"+"       , 5, 0, false, false, true },
	{"~pi~"    , 6, 6, true , false, true },
	{"\""      , 7, 3, true , false, true },
	{"!"       , 7, 0, true , false, true },
	{"?"       , 6, 7, true , false, true },
	{"]"       , 6, 2, true , false, true },
	{"["       , 5, 5, true , false, true },
	{"<"       , 5, 7, true , false, true },
	{">"       , 5, 4, true , false, true },
	{")"       , 4, 0, true , false, true },
	{"("       , 3, 3, true , false, true },
	{"'"       , 3, 0, true , false, true },
	{"&"       , 2, 3, true , false, true },
	{"%"       , 2, 0, true , false, true },
	{"$"       , 1, 3, true , false, true },
	{"#"       , 1, 0, true , false, true },
	{"~arll~"  , 7, 1, false, false, true },
	{"~arup~"  , 6, 6, false, false, true },

	{"a"       , 1, 2, false, false, true }, {"A", 1, 2, true, false, true},
	{"b"       , 3, 4, false, false, true }, {"B", 3, 4, true, false, true},
	{"c"       , 2, 4, false, false, true }, {"C", 2, 4, true, false, true},
	{"d"       , 2, 2, false, false, true }, {"D", 2, 2, true, false, true},
	{"e"       , 1, 6, false, false, true }, {"E", 1, 6, true, false, true},
	{"f"       , 2, 5, false, false, true }, {"F", 2, 5, true, false, true},
	{"g"       , 3, 2, false, false, true }, {"G", 3, 2, true, false, true},
	{"h"       , 3, 5, false, false, true }, {"H", 3, 5, true, false, true},
	{"i"       , 4, 1, false, false, true }, {"I", 4, 1, true, false, true},
	{"j"       , 4, 2, false, false, true }, {"J", 4, 2, true, false, true},
	{"k"       , 4, 5, false, false, true }, {"K", 4, 5, true, false, true},
	{"l"       , 5, 2, false, false, true }, {"L", 5, 2, true, false, true},
	{"m"       , 4, 4, false, false, true }, {"M", 4, 4, true, false, true},
	{"n"       , 4, 7, false, false, true }, {"N", 4, 7, true, false, true},
	{"o"       , 4, 6, false, false, true }, {"O", 4, 6, true, false, true},
	{"p"       , 5, 1, false, false, true }, {"P", 5, 1, true, false, true},
	{"q"       , 7, 6, false, false, true }, {"Q", 7, 6, true, false, true},
	{"r"       , 2, 1, false, false, true }, {"R", 2, 1, true, false, true},
	{"s"       , 1, 5, false, false, true }, {"S", 1, 5, true, false, true},
	{"t"       , 2, 6, false, false, true }, {"T", 2, 6, true, false, true},
	{"u"       , 3, 6, false, false, true }, {"U", 3, 6, true, false, true},
	{"v"       , 3, 7, false, false, true }, {"V", 3, 7, true, false, true},
	{"w"       , 1, 1, false, false, true }, {"W", 1, 1, true, false, true},
	{"x"       , 2, 7, false, false, true }, {"X", 2, 7, true, false, true},
	{"y"       , 3, 1, false, false, true }, {"Y", 3, 1, true, false, true},
	{"z"       , 1, 4, false, false, true }, {"Z", 1, 4, true, false, true},
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

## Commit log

2023-10-25 single controller working with all joystick buttons, plus the possibility to feed keyboard input macros with button presses
2023-10-26 Dual controller support ready for testing with two actual controllers. String feed tested and working, but current hardware layer not correct for full keyboard control.
    [c64b_keyboard.c]
2023-10-29 fixed a few issues and performed more empyrical testing
    [c64b_keyboard.c]
2023-11-02 fixed "left shift" string identifier
    [c64b_keyboard.c]
2023-11-15 a bit of refactoring, several bug fixes and better button mappings. Now also able to start tape/disk via keyboard string feed
    [c64b_keyboard.c]
2023-11-15 fixed a few little bugs and improved welcome menu
    [c64b_keyboard.c, c64b_pinout_0v1.h]
2023-11-15 added btstack libraries for esp32
2023-11-17 corrected license and typos
    [c64b_keyboard.c, c64b_pinout_0v1.h]
2023-11-19 added hardware files
    [blue_64-B_Cu.gbr, blue_64-B_Fab.gbr, blue_64-B_Mask.gbr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]
2023-11-19 adjusted BOM
    [bom.csv]
2023-12-10 updated firmware to new board revision (0.2)
    [blue_64-B_Cu.gbr, blue_64-B_Fab.gbr, blue_64-B_Mask.gbr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]
2023-12-10 updated gerbers, BOM and schematic
    [blue_64-B_Cu.gbr, blue_64-B_Fab.gbr, blue_64-B_Mask.gbr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]
2024-01-07 introduced support for left analog stick as an alternative (non mutually exclusive) to the d-pad, improved latency and responsiveness during event bursts. Increased memory allocation across the board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
2024-01-19 improved button mappings
2024-01-22 improved port swapping and solved issue with restore button being kept low
    [c64b_keyboard.c]
2024-02-04 mapped F1 to Y button
2024-02-19 fixed missing/bad restore key mapping
    [c64b_keyboard.c, c64b_pinout_0v1.h]
2024-02-22 fixed "pi" mapping and restore key not working again (this is going to come back many times in the future))
    [c64b_keyboard.c]
2024-02-23 updated hardware design with new power supply filter
    [blue_64-B_Cu.gbr, blue_64-B_Fab.gbr, blue_64-B_Mask.gbr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]
2024-03-14 improved button mapping and added contact info in README file
2024-03-27 updated schematics
    [blue_64-B_Cu.gbr, blue_64-B_Fab.gbr, blue_64-B_Mask.gbr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]
2024-04-26 selectable and persistent keyboard mapping, on-screen menu now accessible with keyboard only. Re-mapped controller buttons and prepared persistent user-configurable controller mapping
2024-04-28 added video tutorial
    preparing OTA (SD-Card) Update
    removed video
    added video tutorial
    [partitions.csv]
2024-04-30 small stability tweaks and implemented configurable autofire
    [c64b_update.c]
2024-05-03 the thing builds but does not work, and nvs properties are still broken
    [c64b_keyboard.c, c64b_pinout_0v1.h, c64b_pinout_0v2.h]
2024-05-06 everything seems to have been properly migrated. Now running thread-unsafe BTstack functions within the main BTstack thread, and added caps lock indication
2024-05-08 fixed massive lag on gyro controllers and analog sticks, and vibration now only active if leds or lightbar not supported
2024-05-17 Improved on-screen menu system and now keys can be mapped to controller buttons without the need to connect a bluetooth keyboard
2024-05-20 completed version 1.2 with greatly improved button mapping logic
2024-06-18 - implemented proper key precedence for keyboard parser - now on screen menu can be activated with left-Alt too - minor stability fixes
    [c64b_keyboard.c]
2024-07-22 fixed support for triggers with switch controller
2024-09-23 added v1.0 schematic
    [blue_64-B_Cu.gbr, blue_64-B_Fab.gbr, blue_64-B_Mask.gbr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]
2024-09-29 managed to disable pairing while allowing connection of known devices
2024-12-26 added menu entry to forget devices
2025-04-13 switching back to upstream bp32
2025-04-14 bluetooth address now displayed in "Device info" on-screen menu. Restore key now mappable to controller button
2025-04-17 added missing v1 gerbers
    [blue_64-B_Cu.gbr, blue_64-B_Fab.gbr, blue_64-B_Mask.gbr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]
2026-01-27 fixed bug with "restore defaults" displaying the wrong menu entry and fixed switching controller ports being unintentionally allowed from port 1
